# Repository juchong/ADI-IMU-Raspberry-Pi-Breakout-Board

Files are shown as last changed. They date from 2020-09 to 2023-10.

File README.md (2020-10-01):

# ADI IMU Raspberry Pi Breakout Board
A simple Raspberry Pi breakout board (hat) for Analog Devices IMUs.

This board makes interfacing ADI IMUs with any platform that has a 40-pin connector compatible with the Raspberry Pi standard. 

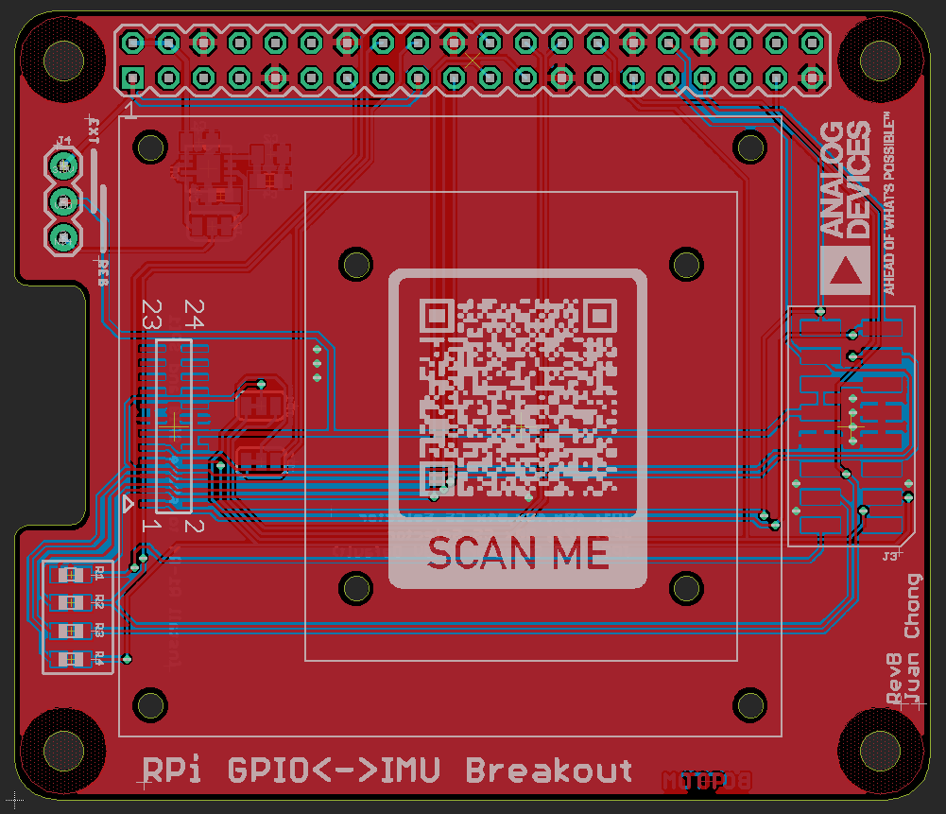
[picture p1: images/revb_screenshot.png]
PCB Screenshot


## Design Features

This breakout board includes features that offer flexibility and expand compatibility with platforms beyond the Raspberry Pi and Jetson Nano. Features include:

1. Compatible with "compact" and "high-performance" ADI IMU families
   1. ADIS1647x
   2. ADIS1650x
   3. ADIS1648x
   4. ADIS1649x
2. Includes solder pads and resistor networks that enable making the following changes
   1. Sharing SPI1 between both sensors, or separating each sensor to it's own port (SPI1 and SPI2)
   2. Connecting the IMU VDD directly to the 5V supply
3. Includes a jumper that bypasses the onboard 3.3V regulator 

## Build Your Own

The PCB design is open-source and licensed under the MIT License. Copies of this circuit board may be purchased from OshPark [here](https://oshpark.com/shared_projects/AxJJlTrH).

| Designator | Value | Sub Allowed? |
| --- | --- | --- |
| J1 | PPTC202LFBN-RC | Y |
| J2 | CLM-112-02-L-D | N |
| J3 | A3-16PA-2SV(71) | Y |
| J4 | 68000-203HLF | Y |
| U1 | ADM7172ACPZ-3.3-R7 | N |
| C1, C2 | 10uF, 0805, 10V | Y |
| C3, C4 | 1uF, 0603, 10V | Y |
| R1, R2, R3, R4 | 0 ohm, 0603 | Y |

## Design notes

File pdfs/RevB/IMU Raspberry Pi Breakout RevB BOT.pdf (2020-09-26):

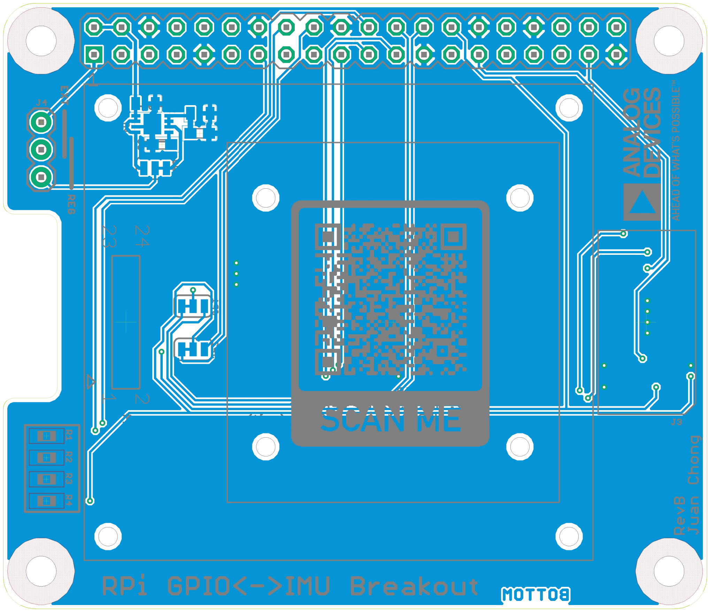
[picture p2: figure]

9/25/2020 9:47 PM f=3.00 C:\Users\Juan\Nextcloud\Eagle\projects\ADI\IMU Raspberry Pi Breakout\IMU Raspberry Pi Breakout RevB.brd

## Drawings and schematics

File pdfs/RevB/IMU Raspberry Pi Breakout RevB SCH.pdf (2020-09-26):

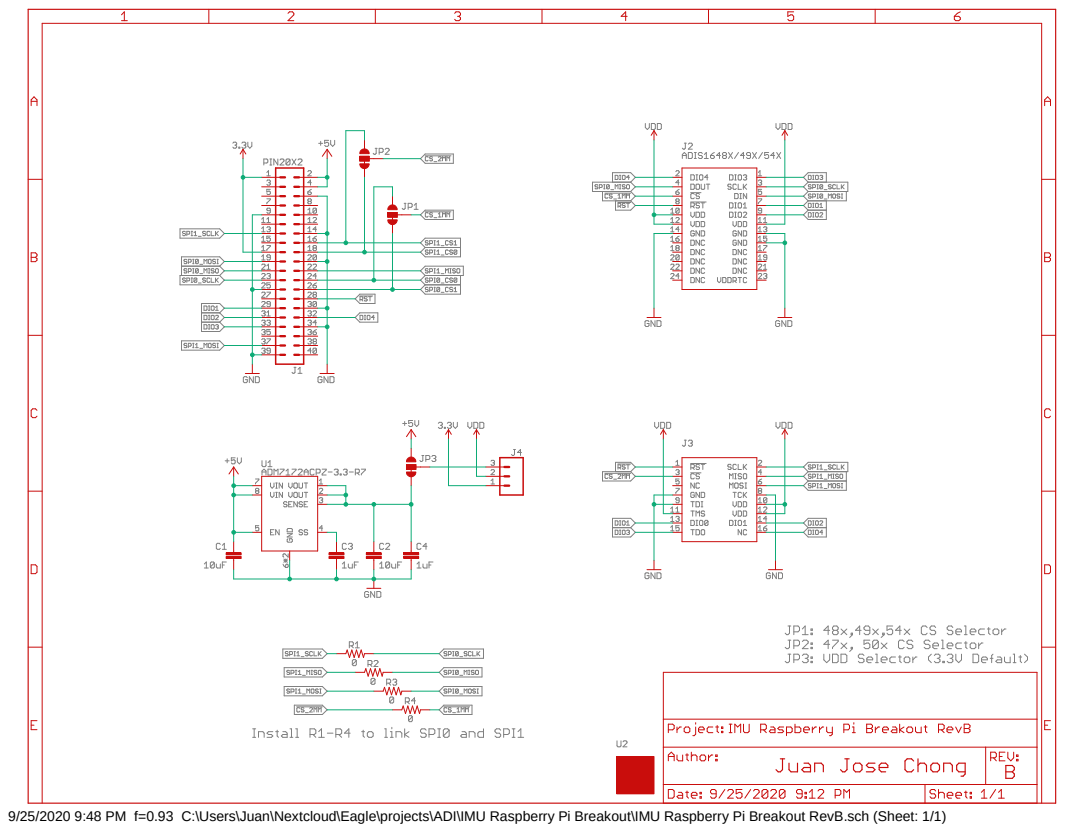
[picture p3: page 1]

9/25/2020 9:48 PM f=0.93 C:\Users\Juan\Nextcloud\Eagle\projects\ADI\IMU Raspberry Pi Breakout\IMU Raspberry Pi Breakout RevB.sch (Sheet: 1/1)

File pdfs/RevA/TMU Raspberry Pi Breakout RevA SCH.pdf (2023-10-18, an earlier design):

A

A

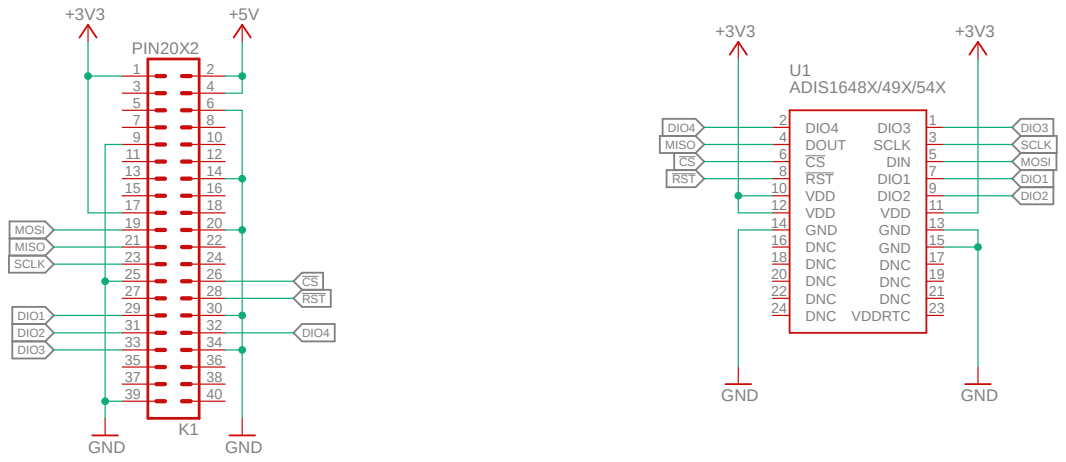
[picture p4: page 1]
PIN20X2; GND; ADIS1648X/49X/54X; DIO3; 1 SCLK; 3 DIN; 5 DIO1; 7 DIO2; 9 VDD; 11 GND; 13 GND; 15 DNC; 17 DNC; 19 DNC; 21 VDDRTC; 23 DNC 24; DNC 22; DNC 20; DNC 18; DNC 16; GND 14; VDD 12; VDD 10; RST 8; DOUT 4; DIO4 2 U1; MOSI MOSI; MISO MISO; RST RST; DIO1 DIO1; DIO2 DIO2; DIO3 DIO3; DIO4 DIO4; SCLK; Project:

TMU Raspberry Pi Breakout RevA

Author: Juan Jose Chong | REV: A

Date: 7/9/2020 2:24 AM | Sheet: 1/1

8/28/2020 8:45 PM f=0.93 C:\Users\Juan\Nextcloud\Eagle\projects\ADI\TMU Raspberry Pi Breakout\TMU Raspberry Pi Breakout RevA.sch (Sheet: 1/1)

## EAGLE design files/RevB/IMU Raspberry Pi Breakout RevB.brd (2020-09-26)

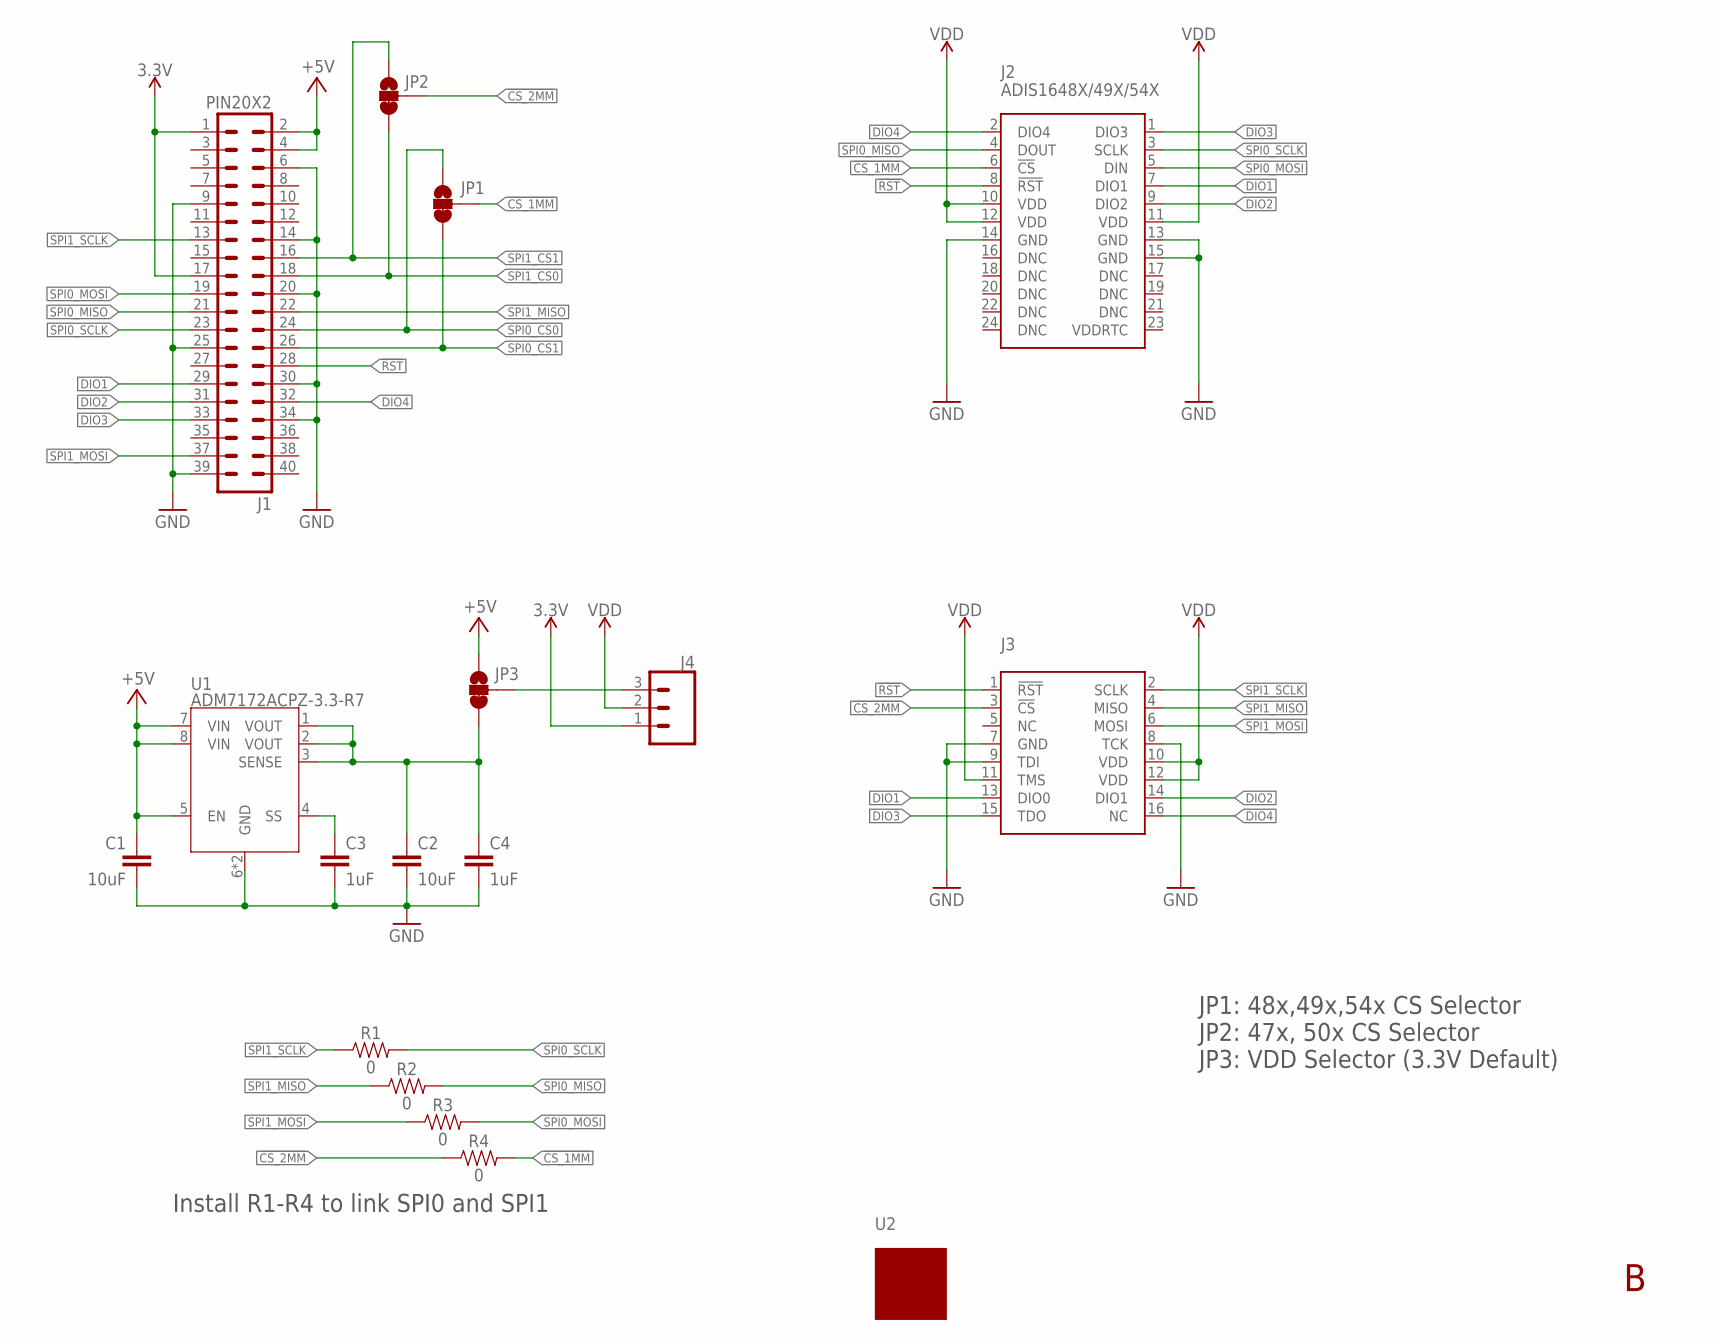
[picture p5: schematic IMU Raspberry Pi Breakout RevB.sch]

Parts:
C1, C2: 10uF; 0805
C3, C4: 1uF; 0603
J1: PIN20X2; PIN_20X2
J2: ADIS1648X/49X/54X; ADIS1648X-TAPPED
J3: ADIS_EVAL_16PIN_2MM; A3-16PA-2SV(71)-TOP
J4: 455-1750-1-ND; 1X03
JP1, JP2, JP3: JUMPER-SMT_3_1-NC_TRACE_SILK; SMT-JUMPER_3_1-NC_TRACE_SILK
R1, R2, R3, R4: 0; 0603
U1: ADM7172ACPZ-3.3-R7; LFCSP-8
U2: ADIS16XXX_COUPON

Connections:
3.3V: J1.1, J1.17, J4.1
!CS_1MM: J2.6 (!CS), JP1.2, R4.2
!CS_2MM: J3.3 (!CS), JP2.2, R4.1
!RST: J1.28, J2.8 (!RST), J3.1 (!RST)
+5V: C1.1, J1.2, J1.4, JP3.1, U1.5 (EN), U1.7 (VIN), U1.8 (VIN)
DIO1: J1.29, J2.7 (DIO1), J3.13 (DIO0)
DIO2: J1.31, J2.9 (DIO2), J3.14 (DIO1)
DIO3: J1.33, J2.1 (DIO3), J3.15 (TDO)
DIO4: J1.32, J2.2 (DIO4), J3.16 (NC)
GND: C1.2, C2.2, C3.2, C4.2, J1.6, J1.9, J1.14, J1.20, J1.25, J1.30, J1.34, J1.39, J2.13 (GND), J2.14 (GND), J2.15 (GND), J3.7 (GND), J3.8 (TCK), J3.9 (TDI), U1.6 (GND), U1.9 (GND)
unnamed: C2.1, C4.1, JP3.3, U1.1 (VOUT), U1.2 (VOUT), U1.3 (SENSE)
unnamed: J4.3, JP3.2
unnamed: C3.1, U1.4 (SS)
SPI0_CS0: J1.24, JP1.1
SPI0_CS1: J1.26, JP1.3
SPI0_MISO: J1.21, J2.4 (DOUT), R2.2
SPI0_MOSI: J1.19, J2.5 (DIN), R3.2
SPI0_SCLK: J1.23, J2.3 (SCLK), R1.2
SPI1_CS0: J1.18, JP2.3
SPI1_CS1: J1.16, JP2.1
SPI1_MISO: J1.22, J3.4 (MISO), R2.1
SPI1_MOSI: J1.37, J3.6 (MOSI), R3.1
SPI1_SCLK: J1.13, J3.2 (SCLK), R1.1
VDD: J2.10 (VDD), J2.11 (VDD), J2.12 (VDD), J3.10 (VDD), J3.11 (TMS), J3.12 (VDD), J4.2

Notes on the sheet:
JP1: 48x,49x,54x CS Selector JP2: 47x, 50x CS Selector JP3: VDD Selector (3.3V Default)
Install R1-R4 to link SPI0 and SPI1

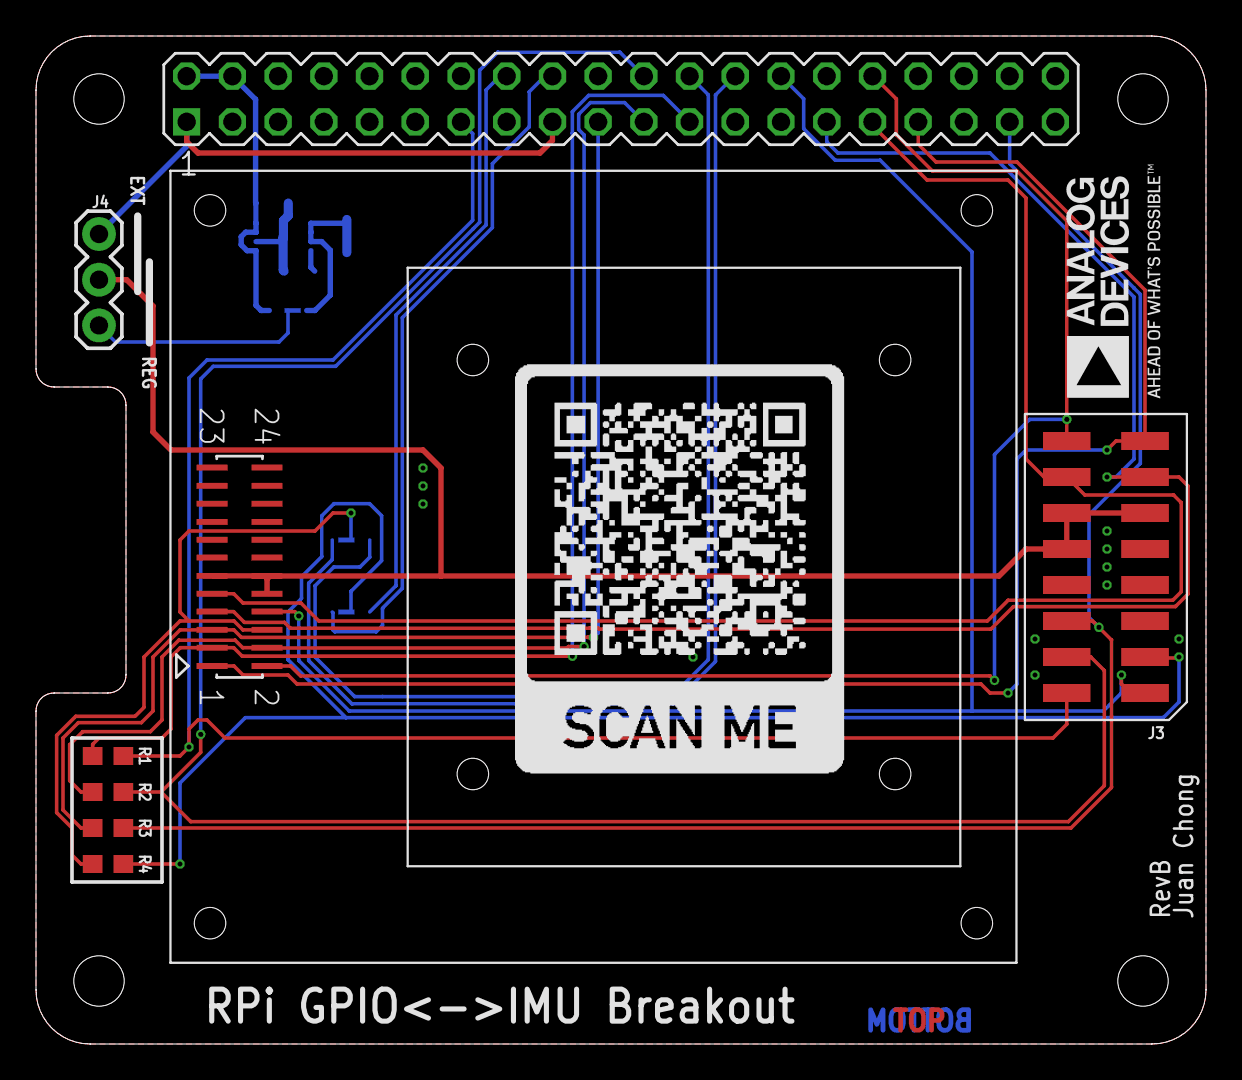
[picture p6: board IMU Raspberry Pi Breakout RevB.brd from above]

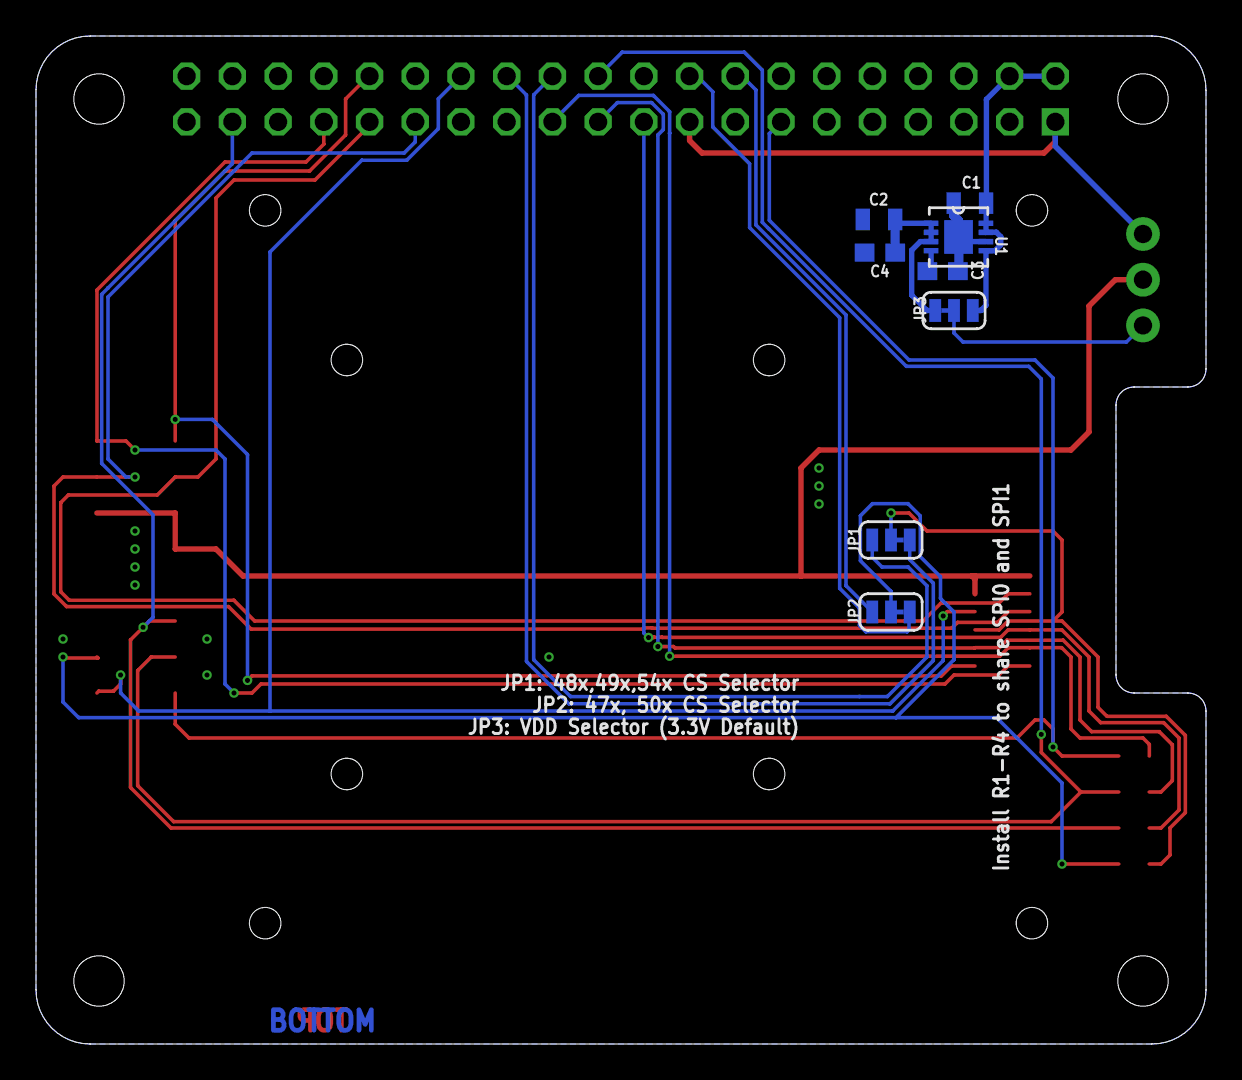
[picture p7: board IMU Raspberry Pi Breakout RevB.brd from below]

Board: 2 copper layers, 65.0 x 56.0 mm, 17 parts (8 on the bottom side), 24 nets.

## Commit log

2020-09-26 Updated design to include resistors that link SPI1 to SPI0. Improved silkscreen art.
    [IMU Raspberry Pi Breakout RevB.brd, IMU Raspberry Pi Breakout RevB.sch]
2023-10-18 Added Rev A
    [IMU Raspberry Pi Breakout RevB.brd, IMU Raspberry Pi Breakout RevB.sch, TMU Raspberry Pi Breakout RevA.brd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]

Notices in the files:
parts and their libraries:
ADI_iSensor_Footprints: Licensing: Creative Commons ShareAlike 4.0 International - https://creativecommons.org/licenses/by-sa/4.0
